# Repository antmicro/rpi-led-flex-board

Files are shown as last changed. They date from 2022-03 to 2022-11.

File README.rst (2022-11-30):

===========================
Raspberry Pi LED Flex Board
===========================

Copyright (c) 2022 `Antmicro <https://www.antmicro.com>`_

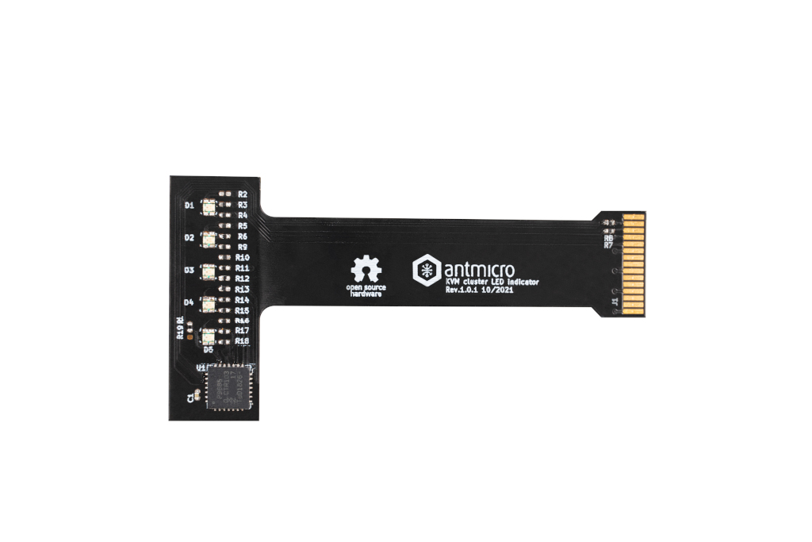
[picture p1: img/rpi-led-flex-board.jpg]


Overview
--------

This repository contains open hardware design files of the LED flexible PCB designed for Raspberry Pi.
It includes a `PCA9685BS <https://www.nxp.com/products/power-management/lighting-driver-and-controller-ics/ic-led-controllers/16-channel-12-bit-pwm-fm-plus-ic-bus-led-controller:PCA9685>`_ GPIO expander which drives five RGB LEDs. 
The GPIO expander is connected to the Raspberry PI over an I2C interface exposed on the camera connector.
This board has been developed and tested with Raspberry Pi 4B.
It has been developed as a part of a compute cluster and fits mechanically in the Open Hardware `Raspberry Pi enclosure <https://github.com/antmicro/rpi-compute-cluster-enclosure>`_.

The design files were prepared in KiCad.
The PCB stackup definition assumes a polyimide, flexible PCB with FR4 stiffeners below the LEDs and the FFC end. 

Repository structure
--------------------
The main repository directory contains KiCad PCB project files, a LICENSE and README.
The remaining files are stored in the following directories:

* ``lib`` - contains the component libraries
* ``img`` - contains graphics for this README

Key features
------------
* 5 x RGB LEDs
* Independent PWM control of the light intensity of each RGB channel in each LED
* I2C communication with Raspberry Pi
* Fits a 15-pin Raspberry Pi camera connector 

License
=======

`Apache-2.0 <LICENSE>`_

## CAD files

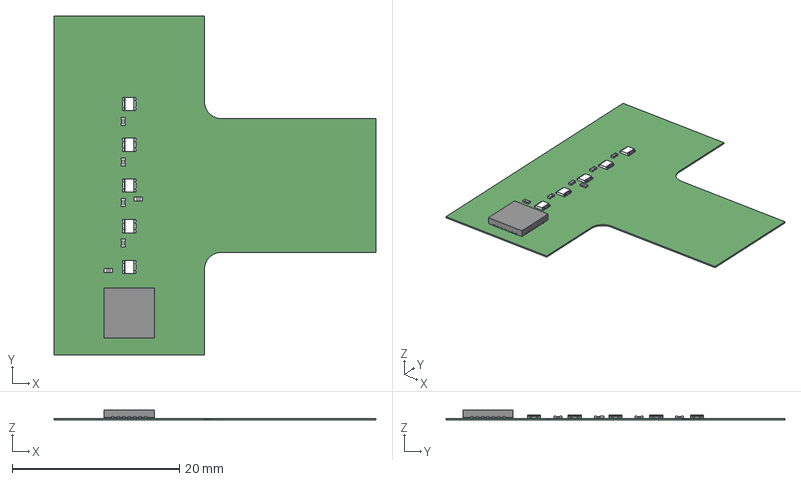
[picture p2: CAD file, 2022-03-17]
3d-model/kvm-compute-cluster-led-indicator.stp
38.5 x 40.5 x 1.25 mm

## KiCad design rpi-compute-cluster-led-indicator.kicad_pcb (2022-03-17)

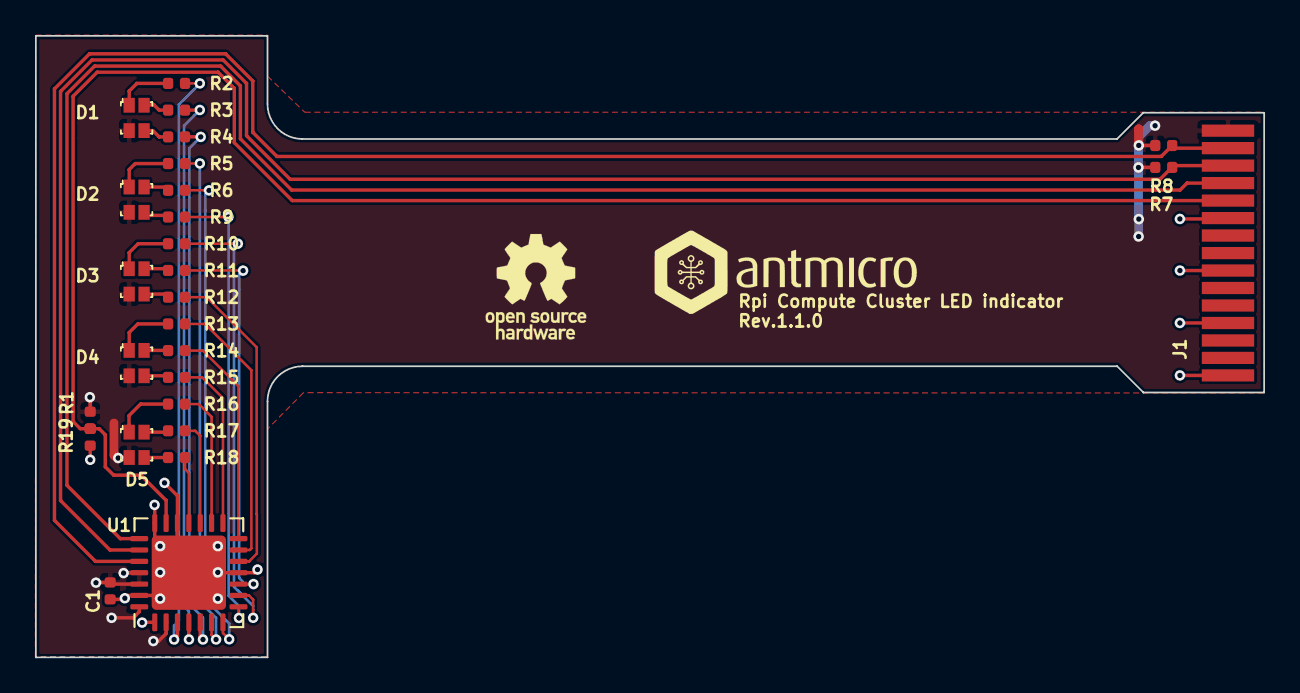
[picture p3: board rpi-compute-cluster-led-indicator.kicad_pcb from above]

Board: 2 copper layers, 70.3 x 35.6 mm, 29 parts (0 on the bottom side), 36 nets.

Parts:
C1: C_100n_0402; 0402-cap
D1, D2, D3, D4, D5: LTST-C19HE1WT; LED_Dual0603
J1: TE_1-1734248-5_FLEX
N1: antmicro_logo; antmicro-logo_scaled_15mm_silk
N2: oshw_logo; OSHW-Logo_5.7x6mm_SilkScreen
R1: R_10k_0402; 0402-res
R2, R5, R10, R13, R16: R_100R_0402; 0402-res
R3, R4, R6, R9, R11, R12, R14, R15, R17, R18: R_49R9_0402; 0402-res
R7, R8: R_4k7_0402; 0402-res
R19: R_0R_0402; 0402-res
U1: PCA9685BS,118; QFN-28_6x6mm_P0.65mm

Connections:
+3V3: C1.2, D1.4, D2.4, D3.4, D4.4, D5.4, J1.15, R1.1, R7.1, R8.1, U1.2, U1.25, U1.26, U1.28
/CLK: J1.12, U1.22
/GPIO: J1.11, R1.2, R19.1, U1.20
/LED_1_B: R4.1, U1.5
/LED_1_G: R3.1, U1.4
/LED_1_R: R2.1, U1.3
/LED_2_B: R9.1, U1.8
/LED_2_G: R6.1, U1.7
/LED_2_R: R5.1, U1.6
/LED_3_B: R12.1, U1.12
/LED_3_G: R11.1, U1.10
/LED_3_R: R10.1, U1.9
/LED_4_B: R15.1, U1.15
/LED_4_G: R14.1, U1.14
/LED_4_R: R13.1, U1.13
/LED_5_B: R18.1, U1.18
/LED_5_G: R17.1, U1.17
/LED_5_R: R16.1, U1.16
/SCL: J1.13, R7.2, U1.23
/SDA: J1.14, R8.2, U1.24
GND: C1.1, J1.1, J1.4, J1.7, J1.10, R19.2, U1.1, U1.11, U1.19, U1.21, U1.27, U1.29
unnamed: D1.1, R2.2
unnamed: D1.2, R3.2
unnamed: D1.3, R4.2
unnamed: D2.1, R5.2
unnamed: D2.2, R6.2
unnamed: D2.3, R9.2
unnamed: D3.1, R10.2
unnamed: D3.2, R11.2
unnamed: D3.3, R12.2
unnamed: D4.1, R13.2
unnamed: D4.2, R14.2
unnamed: D4.3, R15.2
unnamed: D5.1, R16.2
unnamed: D5.2, R17.2
unnamed: D5.3, R18.2

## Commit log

2022-03-17 Add the design files
    [kvm-compute-cluster-led-indicator.kicad_pcb, kvm-compute-cluster-led-indicator.sch, kvm-compute-cluster-led-indicator.stp]
2022-03-17 Add OSHW Logo
    [kvm-compute-cluster-led-indicator.kicad_pcb, kvm-compute-cluster-led-indicator.sch]
2022-03-17 Add stiffener descriptions
    [kvm-compute-cluster-led-indicator.kicad_pcb]
2022-03-17 Add 0R DNP resistor at ~OE pin
    [kvm-compute-cluster-led-indicator.kicad_pcb, kvm-compute-cluster-led-indicator.sch]
2022-03-17 Update shape and placement, reroute the PCB
    [kvm-compute-cluster-led-indicator.kicad_pcb]
2022-03-17 Add minor fixes
    [kvm-compute-cluster-led-indicator.kicad_pcb]
2022-03-17 Add dimmensions
    [kvm-compute-cluster-led-indicator.kicad_pcb]
2022-03-17 Make flex part thinner
    [kvm-compute-cluster-led-indicator.kicad_pcb]
2022-03-17 Move logos
    [kvm-compute-cluster-led-indicator.kicad_pcb]
2022-03-17 Add local libraries
    [kvm-compute-cluster-led-indicator.kicad_pcb, kvm-compute-cluster-led-indicator.sch]
2022-03-17 Update naming convention
    [rpi-compute-cluster-led-indicator.kicad_pcb, rpi-compute-cluster-led-indicator.sch, rpi-compute-cluster-led-indicator.stp]
2022-03-17 Assign revision 1.1.0
    [rpi-compute-cluster-led-indicator.kicad_pcb, rpi-compute-cluster-led-indicator.sch]
2022-03-17 Restore power supply objects
    [rpi-compute-cluster-led-indicator.sch]
2022-03-17 Separate RPi camera ffc symbol from the GPIO controller
    [rpi-compute-cluster-led-indicator.sch]
2022-03-17 Update schematic captions
    [rpi-compute-cluster-led-indicator.sch]
2022-03-17 Add ANT and OSHW logotypes to the sch
    [rpi-compute-cluster-led-indicator.sch]
2022-03-17 Updated SDA connection, checked layout, drc-clean
    [rpi-compute-cluster-led-indicator.kicad_pcb, rpi-compute-cluster-led-indicator.sch]
2022-03-17 Add README
    [rpi-compute-cluster-led-indicator.kicad_pcb, rpi-compute-cluster-led-indicator.stp]
2022-03-17 README: add link to the RPi enclosure
